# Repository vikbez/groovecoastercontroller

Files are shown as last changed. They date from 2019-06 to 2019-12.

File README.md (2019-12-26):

# Groove Coaster Controller
GrooveCoaster Controller replica with dimensions from real cabinet  
Box is 20 x 10 x 56.5 cm

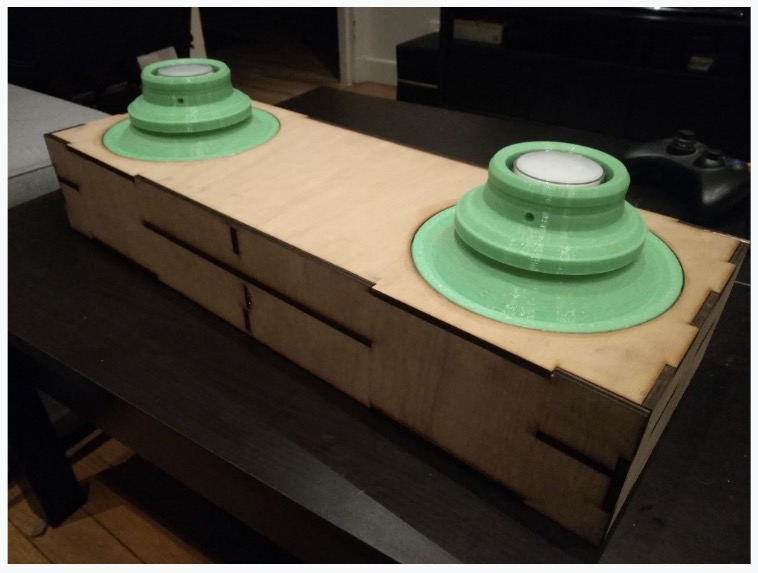
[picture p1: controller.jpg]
controller

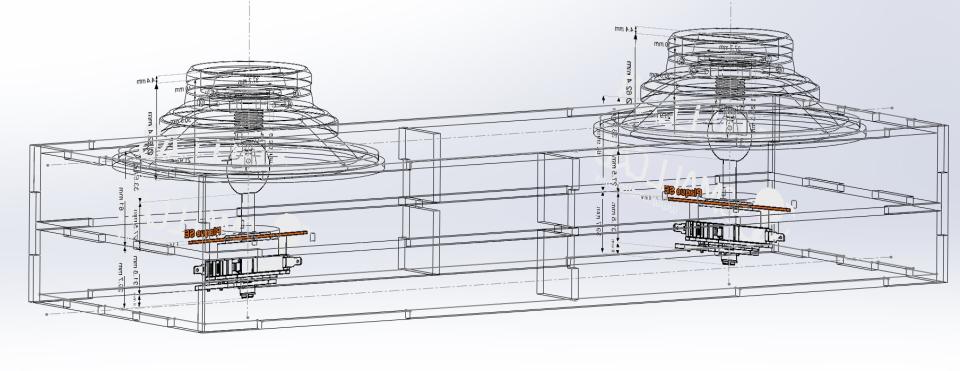
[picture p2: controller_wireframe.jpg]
controller wireframe

(part linking the ls32 and joy_stick is missing in this picture: you can [look at it here](joy_tube.STL))

# needed
- a teensy 3.2 or 3.1
- a 3D printer
- a laser cutting machine
- 5mm plywood
- 2 x seimitsu LS32-SE joysticks
- 2 x 60mm buttons
- 2 screws for locking the top of the sticks
- 2 x large 6mm washers
- 2 x anti vibration 6mm nuts
- 8 x computer fan screws
- wood glue

# things to 3d print
- 2 x joy_stick.stl
- 2 x joy_base.stl
- 2 x joy_tube.stl

# things to laser cut
- 2 x box_side.dxf
- 2 x box_insert.dxf (goes on box_middle, helps for rigidity)
- 1 x box_front.dxf
- 1 x box_front.dxf (with a cut for your usb panel mount adapter)
- 1 x box_top.dxf
- 1 x box_middle.dxf
- 1 x box_bottom.dxf

# assembly
### warning: look at the picture ! be careful on which way goes up during the box assembly ! box_middle should be closer to top, not to bottom
- assemble the printed joy_tube on the ls32 sticks using the washer and the nut
- screw the ls32s to the box_middle (joysticks under the board) using the fan screws
- glue the joy_bases to the box_top (wood glue should do it)
- assemble the sides, front and top panel using the glue
- assemble the 60mm buttons on the joy_sticks, and solder the wires to them
- assemble the joy_sticks on the joy_tube
- solder wires to the ls32s 
- solder everything to the teensy
- assemble bottom panel and then rear panel when you confirmed everything works

# soldering
- Solder a GND wire to all leds and buttons
- Solder pins A5, A6, A7, A8 and 3, 4, 5, 6 to left and right joysticks
- Solder pins A4 and 7 to left and right buttons
- Solder pins A3 and 8 to left and right leds

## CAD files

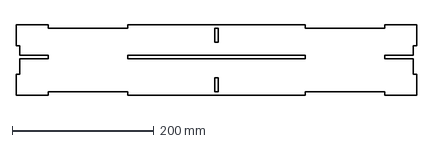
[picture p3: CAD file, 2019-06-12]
box_front.DXF
565.0 x 100.0 mm

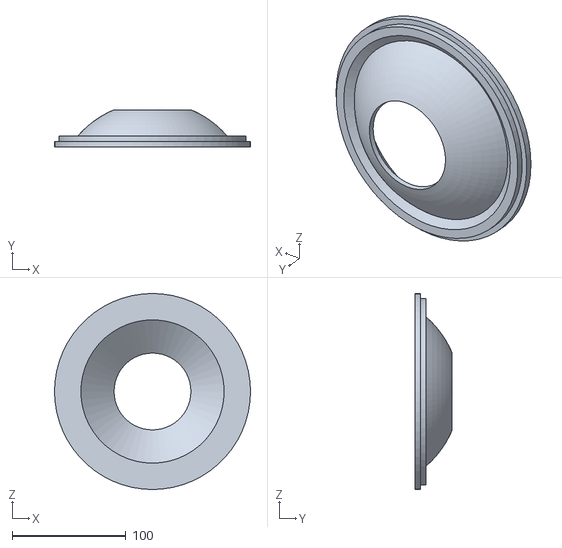
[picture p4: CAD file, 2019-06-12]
joy_base.STL
172.7 x 32.7 x 172.7

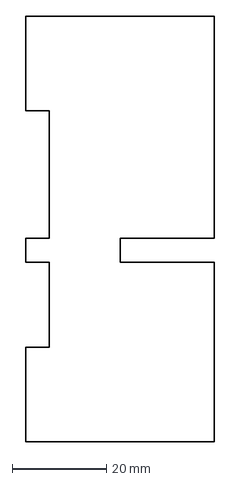
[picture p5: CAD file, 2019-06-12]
box_insert.DXF
40.0 x 90.0 mm

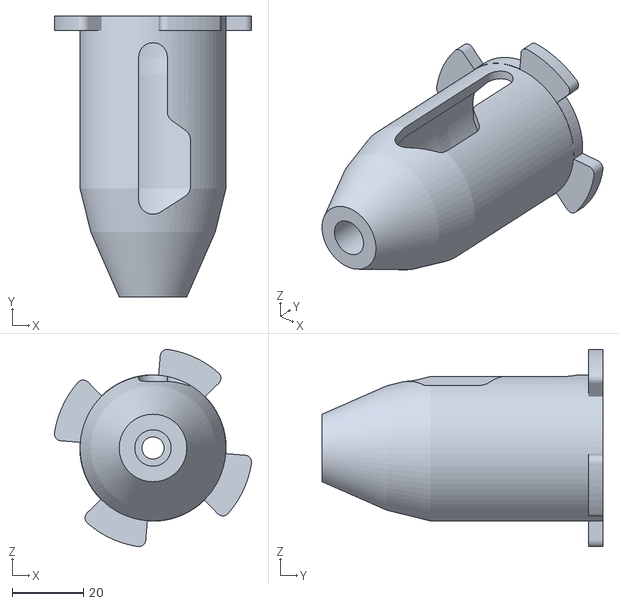
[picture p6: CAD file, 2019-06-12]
joy_tube.STL
55.2 x 78.7 x 55.2

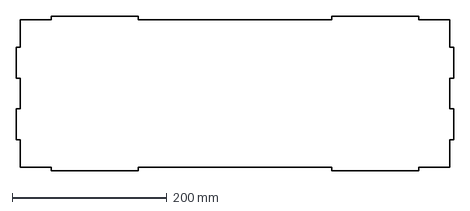
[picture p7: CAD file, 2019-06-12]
box_bottom.DXF
565.0 x 200.0 mm

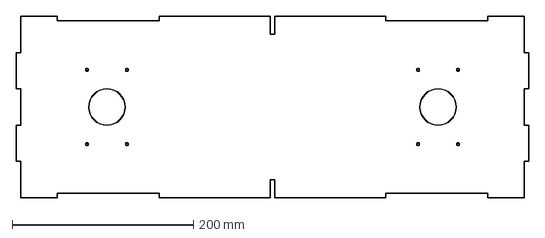
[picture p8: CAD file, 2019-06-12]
box_middle.DXF
565.0 x 200.0 mm

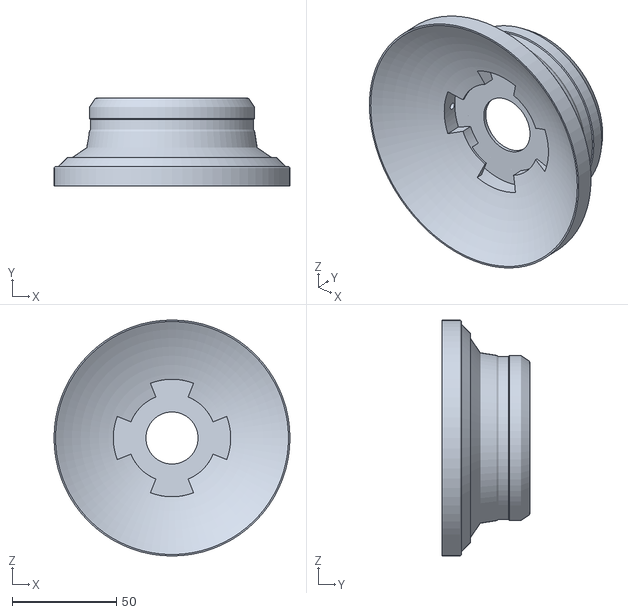
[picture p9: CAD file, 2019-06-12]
joy_stick.STL
113.3 x 42.0 x 113.3

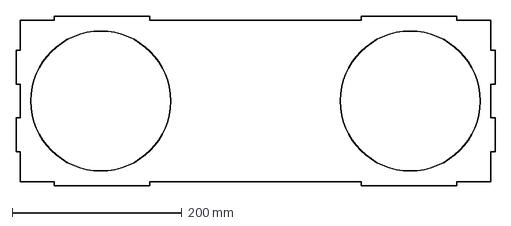
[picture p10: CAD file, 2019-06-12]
box_top.DXF
565.0 x 200.0 mm

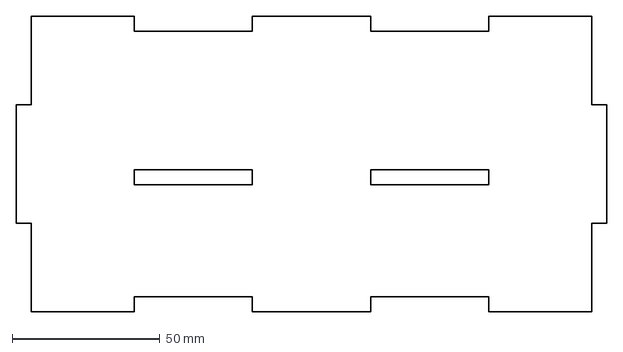
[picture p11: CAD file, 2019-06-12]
box_side.DXF
200.0 x 100.0 mm

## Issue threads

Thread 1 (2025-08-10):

Link "controller_wireframe.jpg" does not give the scheme of the electronics

FransKrau, 2025-08-10:
If I click the "controller_wireframe.jpg" it does not present the scheme how to connect to electronics.
I think the link is wrong.
Can you please provide the correct wireframe?

Frans

Closed 2025-08-11.

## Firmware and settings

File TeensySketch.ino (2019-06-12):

// for teensy 3.1

int input[10] = {3, 4, 5, 6, 7, A8, A7, A6, A5, A4};
unsigned long lastDebounceTime[10] = {0, 0, 0, 0, 0, 0, 0, 0, 0, 0};
unsigned long debounceDelay = 20;
int reading[10] = {0, 0, 0, 0, 0, 0, 0, 0, 0, 0};

int i = 0;

void setup() {
  pinMode(8, OUTPUT); // led right
  pinMode(A3, OUTPUT); // led left
  digitalWrite(8, LOW);
  digitalWrite(A3, LOW);
  Joystick.X(512);
  Joystick.Y(512);
  Joystick.Z(512);
  Joystick.Zrotate(512);
  Joystick.sliderLeft(512);
  Joystick.sliderRight(512);
  Joystick.hat(-1);
  Joystick.useManualSend(true);

  for (i = 0; i < 10; i++) {
    pinMode(input[i], INPUT_PULLUP);
  }
}


void loop() {
  for (i = 0; i < 10; i++) {
    if ((millis() - lastDebounceTime[i]) > debounceDelay) {  
      if (i == 4) {
        digitalWrite(8, !digitalRead(7));
      } else if (i == 9) {
        digitalWrite(A3, !digitalRead(A4));
      }
      
      Joystick.button(i + 1, !digitalRead(input[i]));
      lastDebounceTime[i] = millis();
    }
  }
  Joystick.send_now();
}

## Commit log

2019-06-12 added 2d,3d files and teensy sketch
    [box_bottom.DXF, box_front.DXF, box_insert.DXF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]
2019-06-12 controller wireframe picture
2019-12-26 fix buttons diameter
2019-12-26 fix buttons diameter everywhere
